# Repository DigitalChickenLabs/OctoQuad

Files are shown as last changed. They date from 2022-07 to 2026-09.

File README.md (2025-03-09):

The OctoQuad is an 8-channel quadrature & pulse width decode module. For quadrature signals, position and velocity can be tracked for all 8 channels simultaneously at up to a 250KHz pulse rate (up to 1 million counts/s). For pulse width signals, pulses up to 65535us are supported. With firmware v3, PWM absolute encoders can be tracked accross multiple revolutions. The FTC Edition MK2 board also has an onboard IMU and absolute localizer algorithm intended for use with deadwheel odometry pods.

The channel inputs and I2C lines are protected from ESD to +/- 15kV (air).

Options for interfacing to OctoQuad are very flexible (I2C only on FTC Ed.):

 - I2C (up to 400KHz bus speed)

 - SPI (up to 1MHz bus speed)

 - UART (ASCII-based protocol, 115200 baud, 10-60Hz data output)

 - USB serial (ASCII-based protocol, 10-60Hz data output)

The OctoQuad is perfect for use cases where there is a need to decode many pulse width or high-speed encoder signals, but doing so directly on the system is not feasible. For example, reading quadrature encoders on a Raspberry Pi can be problematic because Linux is not a real-time operating system and does not guarantee accurate timing. Similarly, decoding many high speed quadrature signals on a microprocessor can consume a significant amount of processor time and requires many digital pins. When using an OctoQuad, this processing is offloaded, leaving your processor free for other tasks and removing the need to worry about precise timing.

**All logic and power is 3.3v only! The OctoQuad is not 5v tolerant!**

The OctoQuad can be powered via or USB or via the 3.3v input pin on the board. All channel connections and the dedicated I2C connector use a JST-PH connector, while the auxiliary header uses a standard 0.1" pin spacing.

A wide range of sample code is available, including for Arduino, Raspberry Pi, and PC.

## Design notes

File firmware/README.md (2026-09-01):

# Download OctoQuad Firmware.

**WARNING: Flashing unofficial firmware may cause permanent damage to the OctoQuad, or to devices to which it is connected.**

## Firmware files

From time to time, official firmware updates for the OctoQuad may be released. 
These Official firmware binaries are found here. 

## Note about Firmware Versions

The OctoQuad FTC Edition MK1 shipped with firmare v2. It can, however, be upgraded to firmware v3 to gain support for CRC data validation. The OctoQuad FTC Edition MK2 shipped with firmware v3. It CANNOT be downgraded to firmware v2.

## Flashing firmware

To flash a firmware image onto the OctoQuad, follow the procedure below:

 - Remove all power and data connections from the OctoQuad.
 - Press and hold the BOOTSEL button (‘B’ on resin printed case)
 - While holding BOOTSEL, connect the OctoQuad to a computer using the micro-USB port
 - Wait until the emulated USB drive appears on the computer. The LED will remain off.
 - Drag-n-drop the firmware image onto the emulated USB drive
 - The OctoQuad will automatically flash the firmware and reboot. Flashing is complete when the emulated USB drive disappears and the status LED begins blinking an interface code.

## Release Notes

### v3.1.0

 - Improves IMU stability on FTC Ed MK2
 - Adds diagnostic parameters for the IMU and MCU uptime

### v3.0.11

 - Improves accuracy of absolute localizer velocity on FTC Ed MK2
 - Improves initial IMU calibration accuracy on FTC Ed MK2

### v3.0.10

 - Initial firmware release supporting OctoQuad FTC Ed MK2 (also backwards compatible with other OctoQuad models, to gain support for CRCs on data)
 - Note the register map changed from v2 and driver software will need to be updated accordingly

### v2.0.15

 - Initial firmware release compatible with original OctoQuad and OctoQuad FTC Ed MK1

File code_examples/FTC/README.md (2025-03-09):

# Note about Firmware Versions

The OctoQuad FTC Edition MK1 shipped with firmare v2. It can, however, be upgraded to firmware v3 to gain support for CRC data validation. The OctoQuad FTC Edition MK2 shipped with firmware v3. It CANNOT be downgraded to firmware v2.

# Using the OctoQuad in the FTC SDK

The FTC SDK has a driver built-in for firmware v2. See the example code shipped with the SDK [here](https://github.com/FIRST-Tech-Challenge/FtcRobotController/blob/master/FtcRobotController/src/main/java/org/firstinspires/ftc/robotcontroller/external/samples/Sensor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).

However, for firmwre v3 (which is required for the OctoQuad FTC Edition MK2), you MUST use the driver supplied in this folder. To use this driver, simply copy&paste it into your TeamCode module, and configure the OctoQuad in your robot configuration as "OctoQuad FW v3".

# OctoQuad FTC Edition MK2 Localizer Quickstart

To quickly get up and runnning with the absolute localizer functions of the MK2 board, review the Localizer Quickstart PDF document located in the documentation directory of this repository.

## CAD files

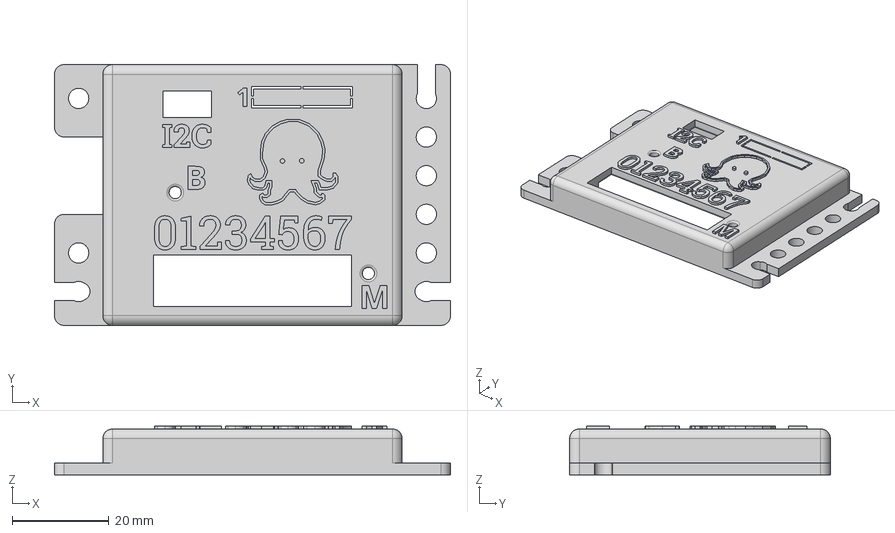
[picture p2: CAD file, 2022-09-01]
mechanical/3D print case/OctoQuad_1.2_SLA_-_Lid.step
82.0 x 54.0 x 10.1 mm

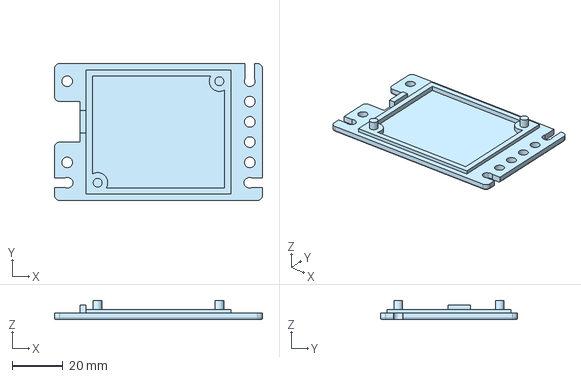
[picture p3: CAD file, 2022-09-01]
mechanical/3D print case/OctoQuad_1.2_SLA_-_Base.step
82.0 x 54.0 x 7.50 mm

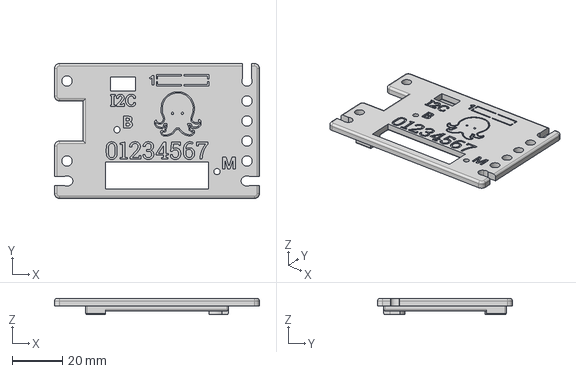
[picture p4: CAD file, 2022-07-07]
mechanical/3D print case/OctoQuad_1.X_FDM_-_Lid.step
82.0 x 54.0 x 6.50 mm

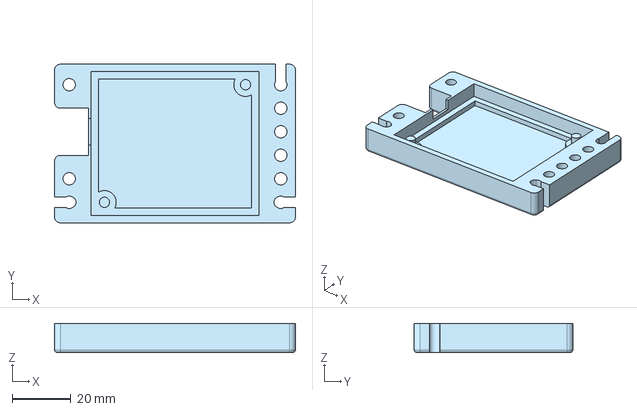
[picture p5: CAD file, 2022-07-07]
mechanical/3D print case/OctoQuad_1.X_FDM_-_Base.step
82.0 x 54.0 x 10.0 mm

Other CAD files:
mechanical/3D print case/OctoQuad_1.2_SLA_-_Base.stl
mechanical/3D print case/OctoQuad_1.X_FDM_-_Base.stl
mechanical/3D print case/OctoQuad_1.X_FDM_-_Lid.stl

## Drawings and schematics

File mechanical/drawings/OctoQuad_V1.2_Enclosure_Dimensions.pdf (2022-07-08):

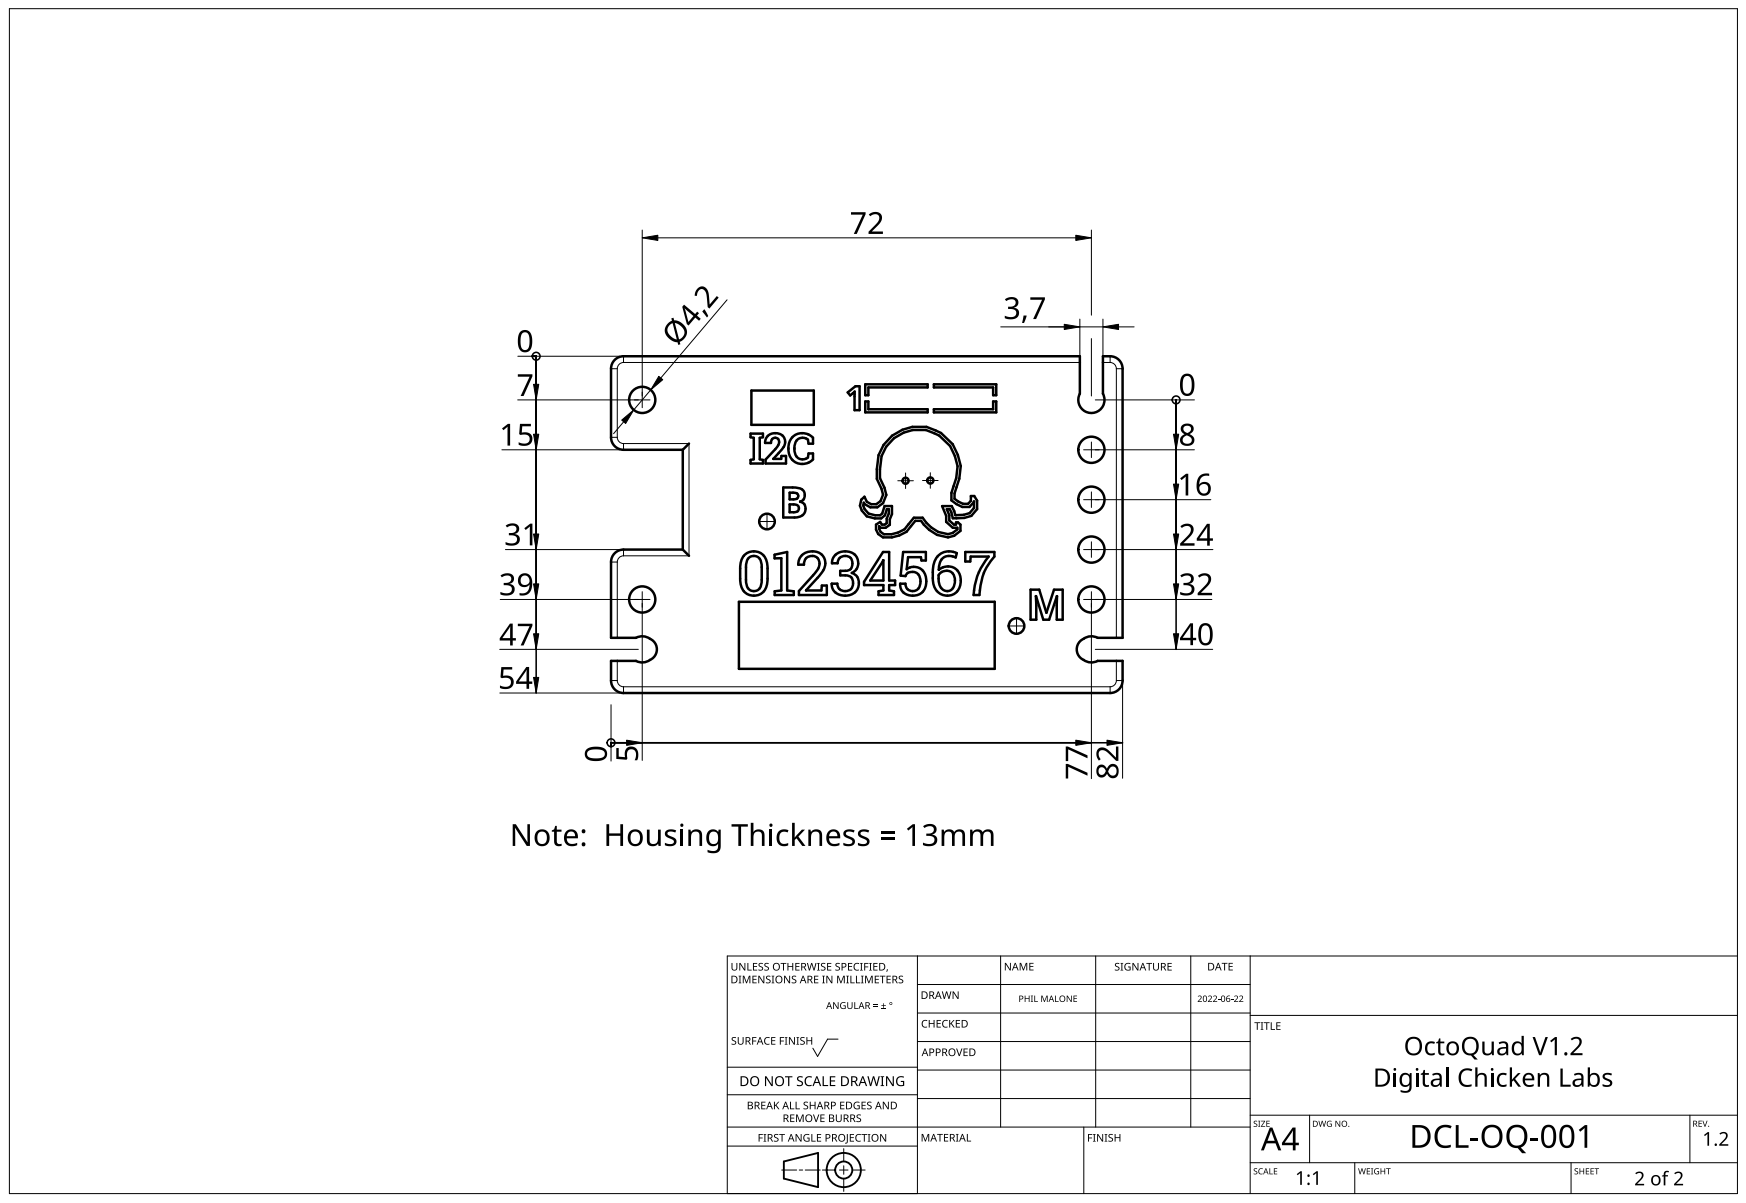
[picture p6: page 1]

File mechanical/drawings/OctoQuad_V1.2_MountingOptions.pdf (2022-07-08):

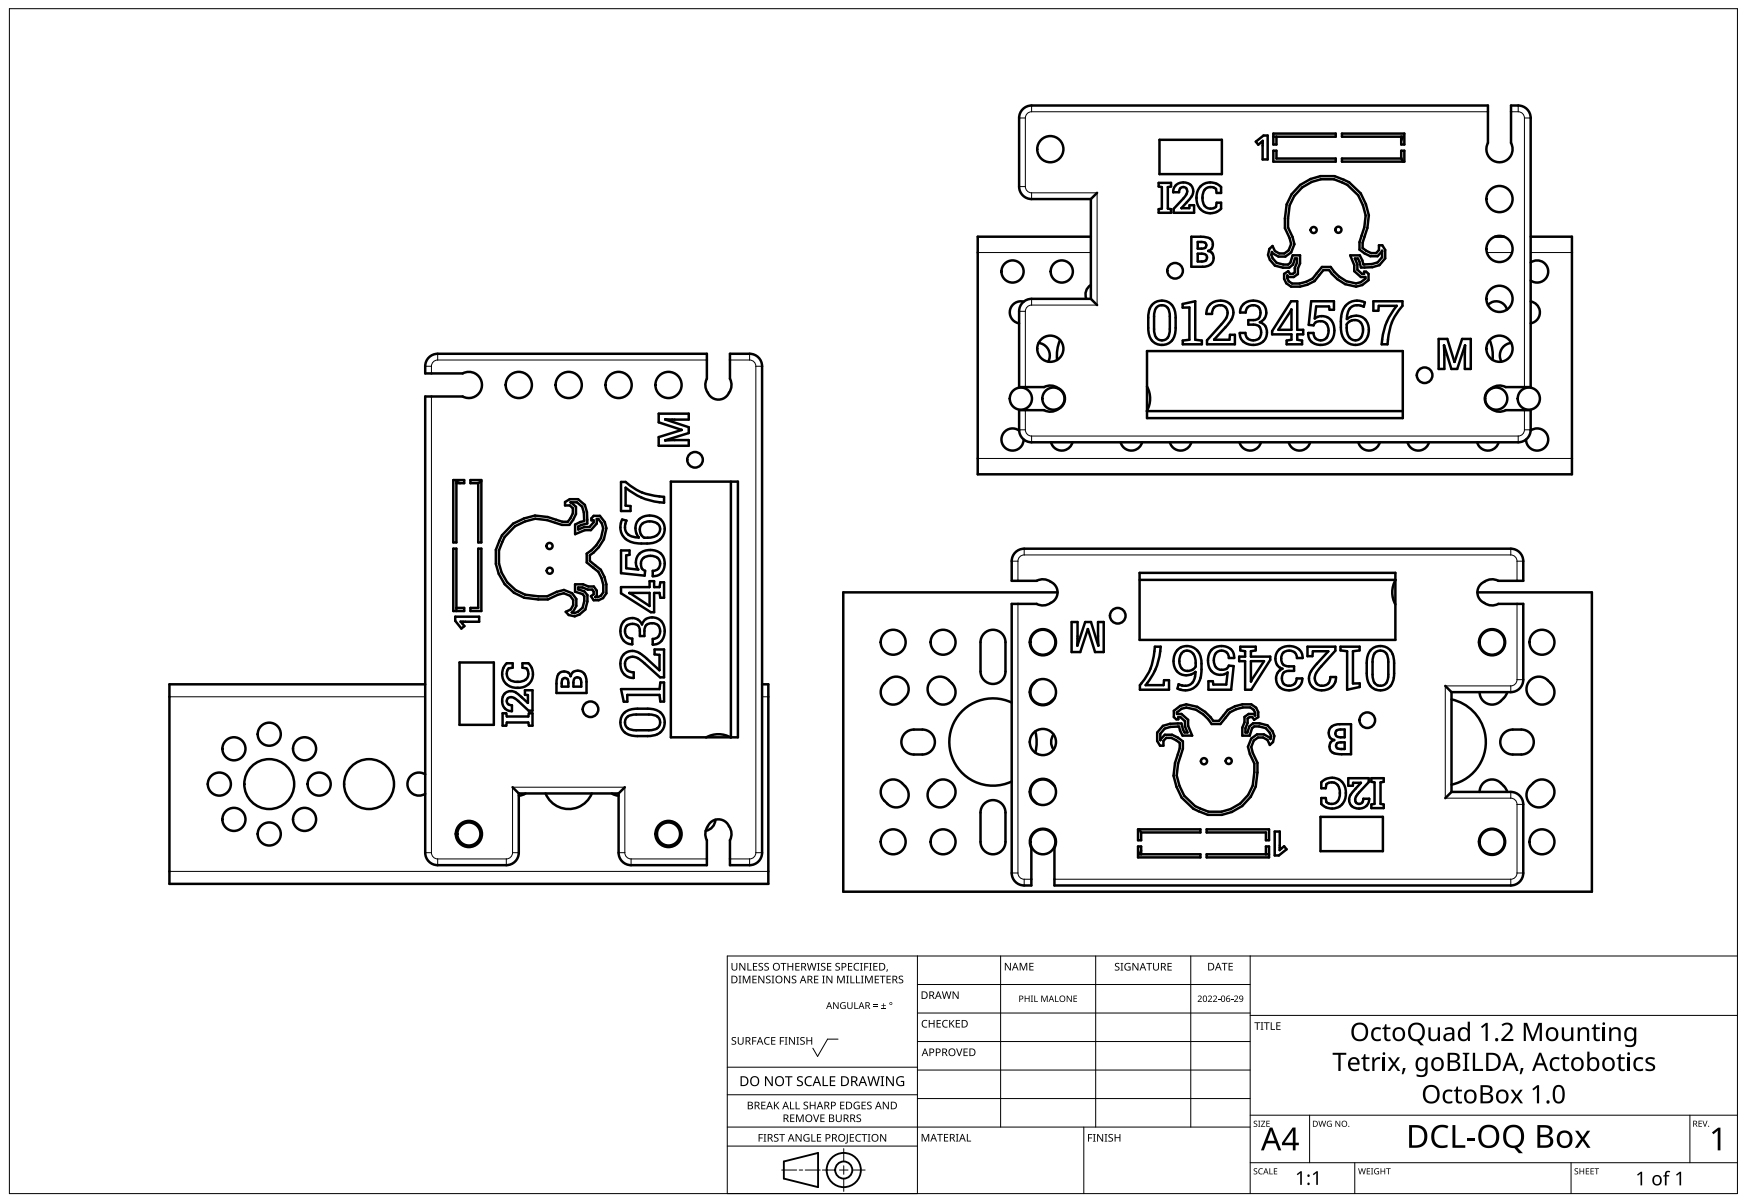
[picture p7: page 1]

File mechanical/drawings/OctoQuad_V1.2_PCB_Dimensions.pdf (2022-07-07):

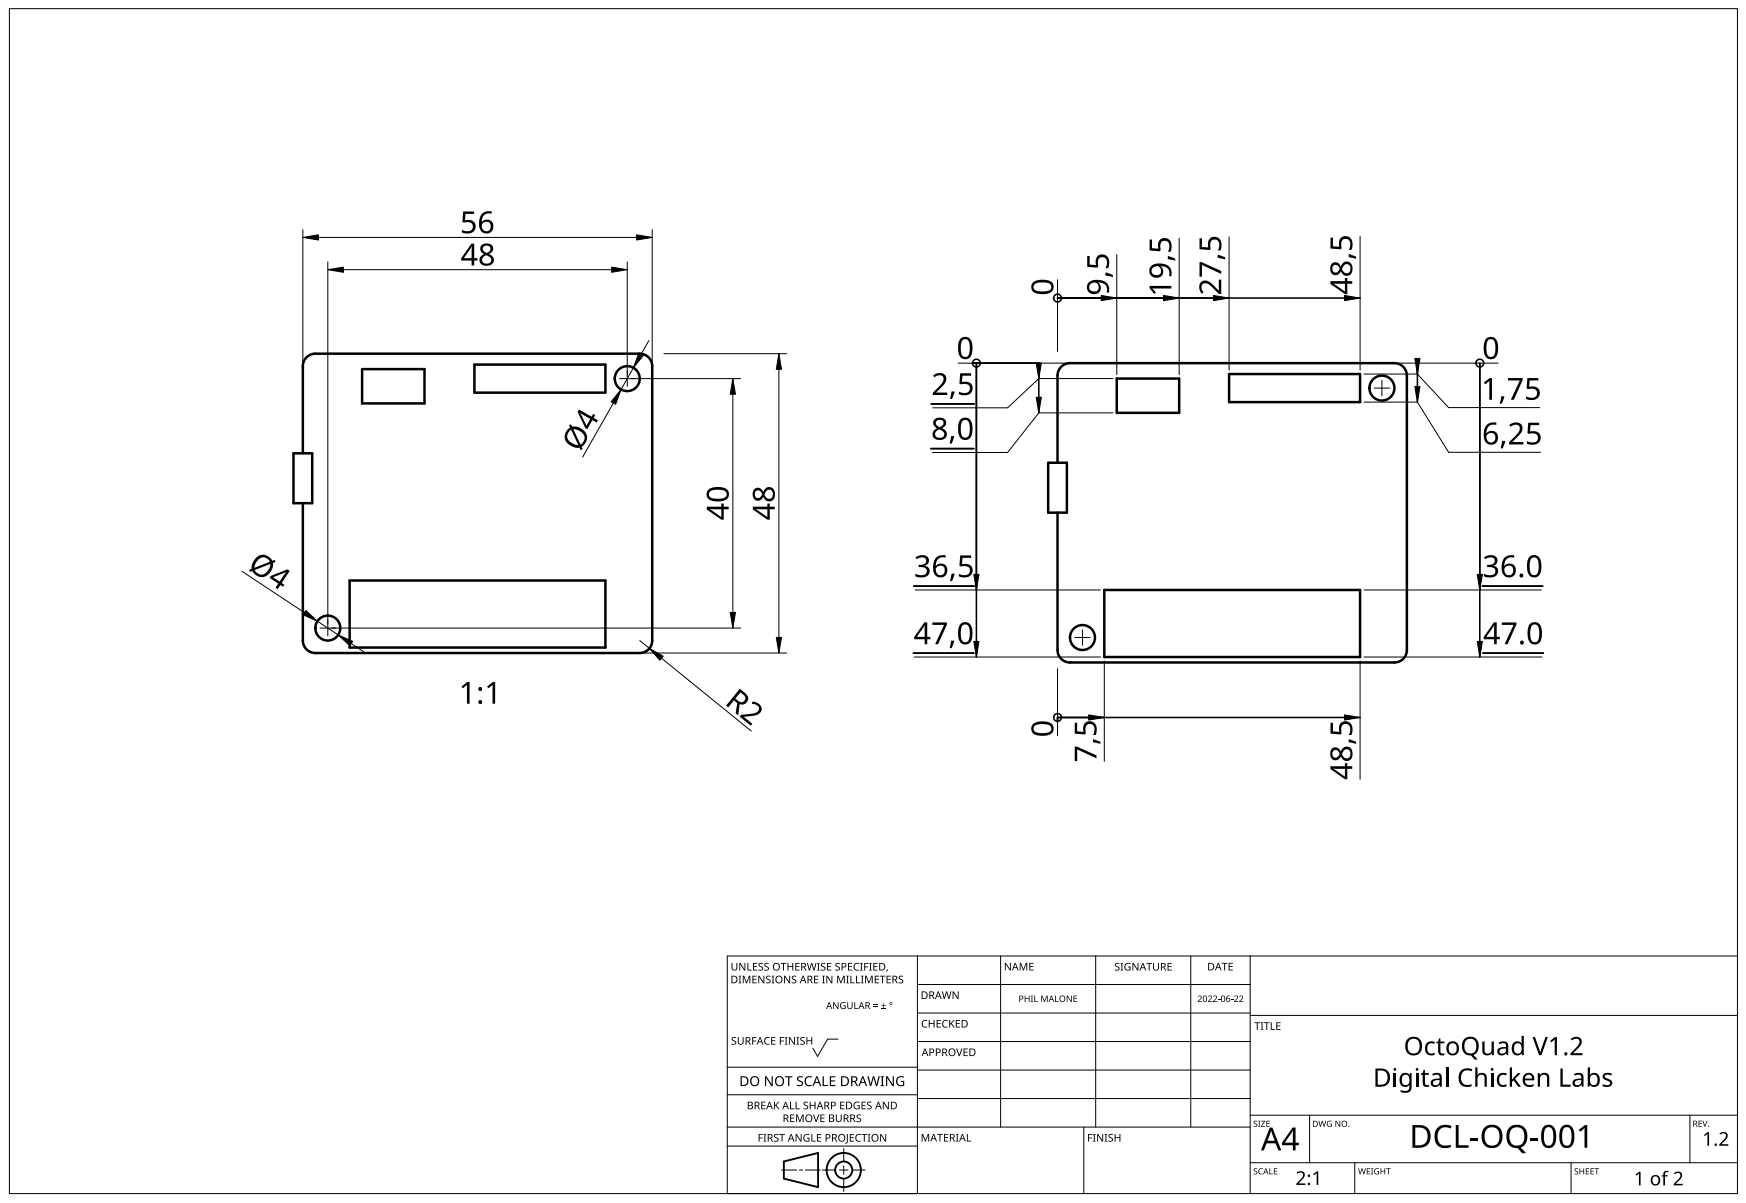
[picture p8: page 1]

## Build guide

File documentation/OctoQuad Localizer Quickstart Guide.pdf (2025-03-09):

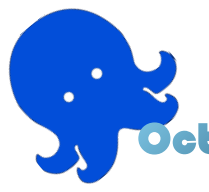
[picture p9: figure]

# OctoQuad Localizer Quickstart

Absolute Localizer Introduction
The OctoQuad FTC Edition MK2 features an onboard IMU and absolute localizer algorithm designed for use with encoders on free-spinning position tracking wheels (“deadwheel odometry pods”) on an FTC robot. The OctoQuad functions as a coprocessor, combining encoder data and IMU data at 1.92KHz to calculate absolute position. This provides excellent position tracking accuracy which is independent of user code execution speed on the host processor. Absolute position data can be queried by the host processor over the I2C interface, along with a cyclic-redundancy-check (CRC) signature to verify the integrity of the received data.

GitHub Repository
This document refers to several files located in the OctoQuad GitHub repository: https://github.com/DigitalChickenLabs/OctoQuad

Absolute Localizer Necessary Configuration
In order to make use of the absolute localizer, the OctoQuad must be informed of some characteristics of your robot and its deadwheel setup.
- Deadwheel encoder ports
- Encoder port directions
- Deadwheel resolutions
- TCP offset
- IMU Scalar
To obtain these values, refer to the setup outline below.

Initial Setup / Calibration Outline
1. Mount the OctoQuad on the robot. Refer to Mounting the OctoQuad on Your Robot.
2. Mount the deadwheels on the robot, one for the X axis and one for the Y axis. Refer to Absolute Coordinate System.
3. Connect the deadwheel encoders to the OctoQuad, making note of the ports on the OctoQuad that you connect them to.
4. Determine if the direction of one (or both) deadwheel encoders must be reversed. Refer to Deadwheel Direction Configuration.

5. Measure the linear resolution of the deadwheel encoders. Refer to Deadwheel Resolution Configuration
6. Measure the IMU heading scalar. Refer to IMU Scalar Calibration.
7. Measure the TCP offset. Refer to Localizer TCP Offset.
8. Plug the determined constants into the LocalizerTest OpMode located in the code_examples/FTC directory of the github repository (https://github.com/DigitalChickenLabs/OctoQuad) and the test localizer accuracy.

Mounting the OctoQuad on Your Robot
The OctoQuad may be mounted on the robot in any of the 6 orientations orthogonal to the direction of gravity. During IMU calibration, the direction of gravity is automatically detected and the appropriate configuration applied to the internal localizer algorithm. The following graphics illustrate acceptable mounting orientations with respect to gravity:

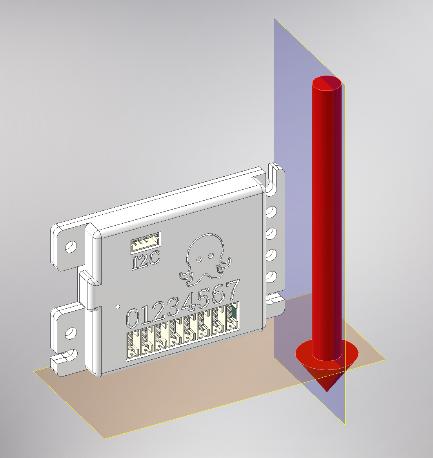
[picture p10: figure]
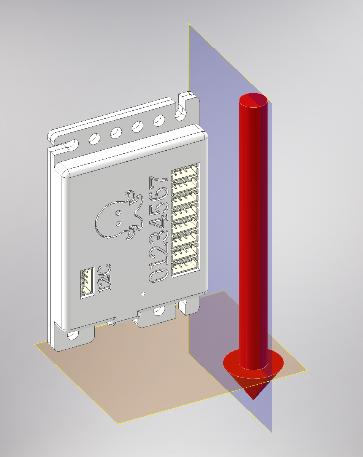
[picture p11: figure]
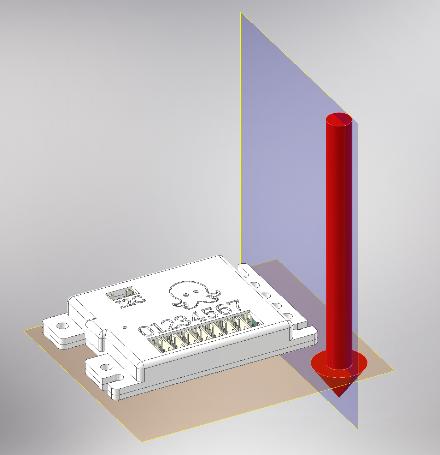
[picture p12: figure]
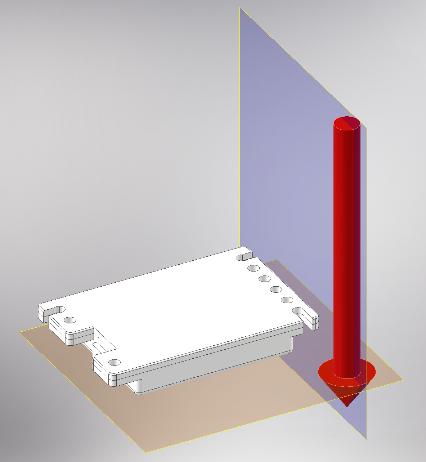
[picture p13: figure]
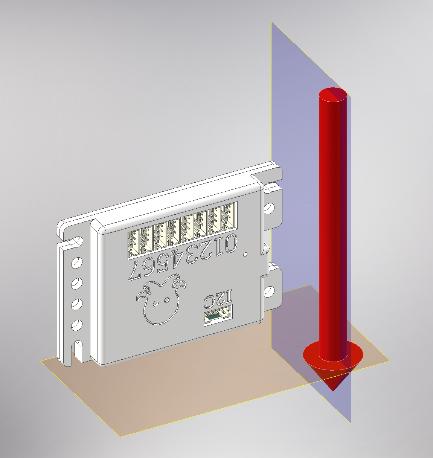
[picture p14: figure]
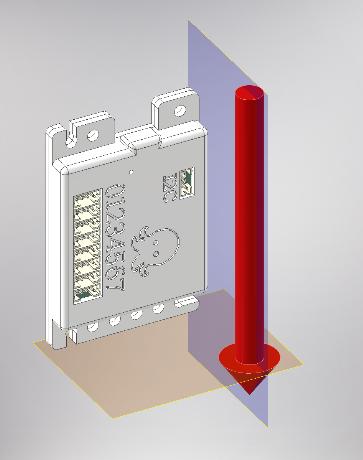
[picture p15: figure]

Absolute Coordinate System
The absolute coordinate system used by the OctoQuad is shown in the figure below. After resetting the localizer, the +X axis points out the front of the robot, and the +Y axis points out the left side of the robot. Counter-clockwise rotation is considered positive. This convention, although at first seemingly counter-intuitive, is chosen for consistency with the cartesian coordinate plane: after calibration, the IMU heading is reset to zero, and moving at an angle of 0 degrees on the cartesian plane means moving in the +X direction.

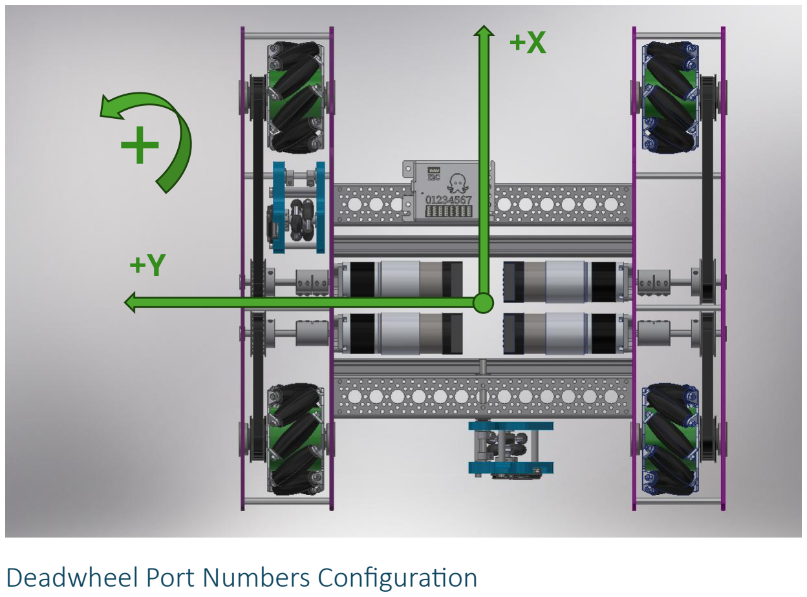
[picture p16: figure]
Deadwheel Port Numbers Configuration

The OctoQuad must be informed of the encoder port numbers to which the deadwheels are connected. To do so, use the following driver function calls when initializing the device:

void setLocalizerPortX(int port)

void setLocalizerPortY(int port)
Deadwheel Direction Configuration
The direction of the encoder ports to which the deadwheels are connected must be configured such that, with the robot oriented at 0 degrees, pushing the robot in the +X direction results in an increasing encoder count on the X deadwheel, and likewise, pushing the robot in the +Y direction results in an increasing encoder count on the Y deadwheel

(see Absolute Coordinate System). A helper OpMode is available to aid in determining this, as well as the deadwheel resolution (see below). If reversing is necessary, use the following driver function call for each deadwheel when initializing the device:

void setSingleEncoderDirection(int port, EncoderDirection direction)
Deadwheel Resolution Configuration
Because the number of deadwheel encoder ticks generated for a given robot travel distance depends on both the resolution of the encoder and diameter of the wheel, the localizer must be informed (for both axes) of how many encoder ticks correspond to one millimeter of travel. Although a theoretical value may be calculated for this based on the hardware used on the robot, it is NOT recommended to do so. Rather, an empirical measurement over several meters of travel is suggested. An OpMode is available which provides a guided process for completing these steps (DeadwheelCalibator in the code_examples/FTC directory of the GitHub repository). (https://github.com/DigitalChickenLabs/OctoQuad) Alternatively, if you already know these constants based on specifications provided by the deadwheel manufacturer, you may use those constantly directly instead. For example, values for GoBilda odometry pods are available here. (https://github.com/goBILDA-Official/FtcRobotController-Add-Pinpoint/blob/goBILDA-Odometry-Driver/TeamCode/src/main/java/org/firstinspires/ftc/teamcode/GoBilda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) Once the constants have been determined, they may be applied using the following driver function calls when initializing the device:

void setLocalizerCountsPerMM_X(float ticksPerMM_x)

void setLocalizerCountsPerMM_Y(float ticksPerMM_y)
IMU Scalar Calibration
The OctoQuad self-calibrates the zero-angular-velocity bias of the IMU. However, it cannot automatically calibrate the angular velocity scale factor for the IMU. It is critical to calculate this scale factor in order to obtain accurate heading data. Incorrect scalars will not cause heading drift – but they will result in the IMU reporting more/less degrees of rotation than it was truly rotated. An OpMode is available which provides a guided process for completing this calibration (HeadingScalarCalibrator in the code_examples/FTC directory of the GitHub repository). (https://github.com/DigitalChickenLabs/OctoQuad) Once the scale factor has been determined, it may be set using the following driver function call:

void setLocalizerImuHeadingScalar(float headingScalar)
Localizer TCP Offset
The Tracking Center Point (TCP) is the “datum point” on the robot to which the robot’s XY displacement relative to the origin of the absolute coordinate system is measured. An important characteristic of the TCP is that it is the point about which a rotation does not influence the reported displacement. Imagine putting an orange sticker on a corner of the robot (call this the TCP). If you then rotate the robot with the orange sticker being the center of rotation, the physical location of the orange sticker will not change. If you measure the displacement of the orange sticker relative to the playing field before and after rotating the robot, it will be exactly the same.
With deadwheel odometry, the initial mathematical location of the TCP is at the intersection of lines drawn through the deadwheels and parallel to their respective

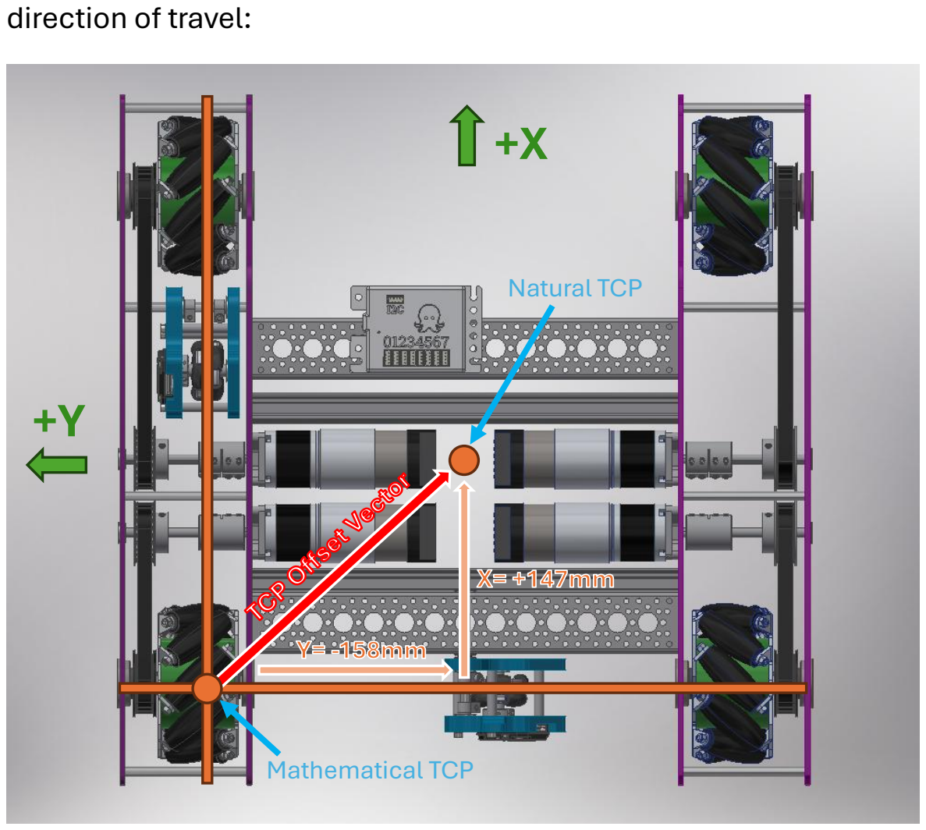
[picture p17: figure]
direction of travel:; Mathematical TCP; Natural TCP

The initial mathematical TCP is located at this intersection because it is the location where, if it is the center of rotation, the odometry wheels experience no normal motion (only tangential). Said another way, rotating about this point causes the odometry wheels to exclusively slide laterally rather than rotate axially. Thus, because there is no axial rotation, the reported XY displacement remains constant.
This initial mathematical location of the TCP can prove rather inconvenient, because it is NOT coincident with the robot’s natural center of rotation, i.e. its geometric center. This means that, initially, the displacement of the robot in the absolute coordinate system is not being measured relative to its natural center of rotation. This has the effect of the reported X and Y positions “wobbling” in a sinusoidal fashion if the robot is rotated about its natural center of rotation. Thus, it is often convenient to, in software, relocate the TCP to be coincident with the robot’s geometric center.
The TCP offsets are defined as the vector which points from the initial mathematical TCP location to the desired/natural TCP location, in the coordinate system defined in Absolute Coordinate System. In the example situation shown in the figure, the X offset is +147mm and the Y offset is -158mm because to relocate the mathematical TCP to the natural TCP, it must be moved <+147, -158> in the coordinate system. These distances can be measured with a tape measure; it is not critical to tracking accuracy for them to be exact.
Once the desired offsets have been determined, they may be applied using the following driver function calls when initializing the device:

void setLocalizerTcpOffsetMM_X(float tcpOffsetMM_X)

void setLocalizerTcpOffsetMM_Y(float tcpOffsetMM_Y)
Localizer Velocity Calculation Interval
The localizer calculates the velocity in the absolute coordinate frame at a fixed interval (by default, 25ms). Longer periods give higher resolution with more latency, shorter periods give lower resolution with less latency. If you wish to change this interval from its default value, use the following driver function call when initializing the device:

void setLocalizerVelocityIntervalMS(int ms)
CRC Data Integrity Check
The I2C bus protocol does not have any data integrity guarantee mechanisms built into it by default. In FTC, ESD events can cause corrupted I2C data. Additionally, it has been observed that the Control Hub and Expansion Hub appear to have a hardware bug wherein motor switching noise can cause the I2C peripheral to become confused and send invalid I2C clock pulses that violate timing, which also causes corrupted data. One frequently observed symptom of this is getting “NaN” results from an I2C device. In order to mitigate these issues, the OctoQuad supplies a CRC signature along with the data in order to validate the integrity of the data on the receiving end.

Both the EncoderDataBlock and LocalizerDataBlock data structures contain a crcOk
boolean field which reports whether or not the data is valid. If this flag is not set, you should throw away the data and attempt a read again.

Device Initialization
When initializing the device from user code, follow the following procedure (this is also illustrated in the LocalizerTest OpMode located in the code_examples/FTC directory of the github repository): (https://github.com/DigitalChickenLabs/OctoQuad)
1. Retrieve the device handle from the HardwareMap
2. Configure all necessary localizer parameters (refer to Absolute Localizer Necessary Configuration)
3. Apply the parameters and calibrate the IMU by calling
resetLocalizerAndCalibrateIMU()
4. Wait for the localizer status to report RUNNING before querying position data
5. Make sure to check crcOk when polling position data!

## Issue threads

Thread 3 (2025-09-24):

Spurious firmware version numbers from an FTC MK1

manthey, 2025-09-24:
Our FTC team (Robovines 6955 -- I'm a programming mentor) has been using the FTC MK1 octoquad since last season.  We specifically are using it with 3 gobilda odopods.  We got occasional spurious values (seemingly bit flips) through the i2c bus, and had added our own code to detect when the values were clearly wrong and ignore them (this mostly worked but occasionally we would take a modestly wrong value).

We just upgraded to the V3 firmware and are using the code provided from this library.  The `isDataValid()` method works as desired -- when that check passes, all of our data looks good.

Fairly often, however, the driver control hub prints a warning about an incompatible firmware version (the "OctoQuad is running a different major firmware version than this driver was built for ..." message or the "OctoQuad does not report correct CHIP_ID value" message).  Printing the firmware version string, we see that it often has bad values (often 3.0.10 as we'd expect but sometimes 131.0.10 and sometimes 127.255.255).  We get the same results regardless of which rev hub or expansion hub and which i2c port we plug into.  This happens even when we aren't operating motors.  Other i2c devices are plugged in to other i2c ports.

Have you seen this before?  It isn't causing any functional issue, because we guard the actual reads with the `isDataValid` method.  We can obviously suppress the warning messages, but we'd rather have less spurious values.

Thank you.

Windwoes, 2025-09-25:
Hey there - we have seen those errors happen rarely before, but in those instances, the reported values were all zeros and it appeared the I2C controller in the Expansion Hub had gotten into a bad state.

Getting seemingly corrupted I2C frames even when not running motors is a head scratcher for sure. Do you have any equipment (oscilloscope or logic analyzer) to capture what is actually happening on the bus?

manthey, 2025-09-25:
Yes -- I'll see if I can put an o-scope on it at our next meeting and see if I can learn what is going on.  I'll also try it on a completely different control hub with a different connector.

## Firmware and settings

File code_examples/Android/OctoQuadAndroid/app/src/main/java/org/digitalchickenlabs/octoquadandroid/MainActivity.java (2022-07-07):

/*
 * Copyright (c) 2022 DigitalChickenLabs
 *
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
 * The above copyright notice and this permission notice shall be included in all
 * copies or substantial portions of the Software.
 * THE SOFTWARE IS PROVIDED "AS IS", WITHOUT WARRANTY OF ANY KIND, EXPRESS OR
 * IMPLIED, INCLUDING BUT NOT LIMITED TO THE WARRANTIES OF MERCHANTABILITY,
 * FITNESS FOR A PARTICULAR PURPOSE AND NONINFRINGEMENT. IN NO EVENT SHALL THE
 * AUTHORS OR COPYRIGHT HOLDERS BE LIABLE FOR ANY CLAIM, DAMAGES OR OTHER
 * LIABILITY, WHETHER IN AN ACTION OF CONTRACT, TORT OR OTHERWISE, ARISING FROM,
 * OUT OF OR IN CONNECTION WITH THE SOFTWARE OR THE USE OR OTHER DEALINGS IN THE
 * SOFTWARE.
 */

package org.digitalchickenlabs.octoquadandroid;

import android.app.Activity;
import android.content.Intent;
import android.os.Bundle;
import android.view.View;
import android.widget.Button;
import android.widget.LinearLayout;
import android.widget.TextView;

import java.nio.charset.StandardCharsets;
import java.util.ArrayList;
import java.util.concurrent.CountDownLatch;

public class MainActivity extends Activity implements UsbCdcAcmSerialPortManager.Callback
{
    UsbCdcAcmSerialPortManager serialPortManager;

    TextView connectionStatus;
    LinearLayout layoutEncoders;
    TextView enc0, enc1, enc2, enc3, enc4, enc5, enc6, enc7;
    Button btnReset;

    UsbCdcAcmSerialPort octoquad;

    UiUpdaterThread uiUpdaterThread;

    @Override
    protected void onCreate(Bundle savedInstanceState)
    {
        super.onCreate(savedInstanceState);
        setContentView(R.layout.activity_main);

        connectionStatus = (TextView) findViewById(R.id.connectionStatus);
        layoutEncoders = (LinearLayout) findViewById(R.id.encoders);
        btnReset = (Button) findViewById(R.id.btnReset);
        enc0 = (TextView) findViewById(R.id.enc0);
        enc1 = (TextView) findViewById(R.id.enc1);
        enc2 = (TextView) findViewById(R.id.enc2);
        enc3 = (TextView) findViewById(R.id.enc3);
        enc4 = (TextView) findViewById(R.id.enc4);
        enc5 = (TextView) findViewById(R.id.enc5);
        enc6 = (TextView) findViewById(R.id.enc6);
        enc7 = (TextView) findViewById(R.id.enc7);

        layoutEncoders.setVisibility(View.INVISIBLE);

        serialPortManager = UsbCdcAcmSerialPortManager.getInstance(this);
        serialPortManager.registerCallback(this);

        ArrayList<UsbCdcAcmSerialPort> ports = serialPortManager.getCurrentlyKnownDevices();

        if(ports.size() > 0)
        {
            onDeviceConnected(ports.get(0));
        }

        btnReset.setOnClickListener(new View.OnClickListener()
        {
            @Override
            public void onClick(View v)
            {
                synchronized (MainActivity.this)
                {
                    if(uiUpdaterThread != null)
                    {
                        uiUpdaterThread.sendCommand('R');
                    }
                }
            }
        });
    }

    @Override
    protected void onNewIntent(Intent intent)
    {
        super.onNewIntent(intent);
        serialPortManager.onNewIntent(intent);
    }

    @Override
    protected void onDestroy()
    {
        super.onDestroy();
        serialPortManager.unregisterCallback(this);
    }

    @Override
    public synchronized void onDeviceConnected(UsbCdcAcmSerialPort dev)
    {
        if(octoquad == null)
        {
            octoquad = dev;
            uiUpdaterThread = new UiUpdaterThread(octoquad);
            uiUpdaterThread.start();

            layoutEncoders.setVisibility(View.VISIBLE);
            connectionStatus.setText("OctoQuad Connected");
            connectionStatus.setTextColor(getColor(R.color.colorConnected));
        }
    }

    @Override
    public synchronized void onDeviceDisconnected(UsbCdcAcmSerialPort dev)
    {
        if(dev == octoquad)
        {
            if(uiUpdaterThread != null)
            {
                uiUpdaterThread.shutdownAndAwaitTermination();
                uiUpdaterThread = null;
                octoquad = null;

                layoutEncoders.setVisibility(View.INVISIBLE);
                connectionStatus.setText("OctoQuad Not Connected");
                connectionStatus.setTextColor(getColor(R.color.colorNotConnected));
            }
        }
    }

    @Override
    public void onDeviceOpenFailed(UsbCdcAcmSerialPort dev, UsbCdcAcmSerialPort.OpenResultCode code)
    {

    }

    class UiUpdaterThread extends Thread
    {
        CountDownLatch latch = new CountDownLatch(1);
        byte[] readBuf = new byte[1];
        byte[] lineBuf = new byte[256];
        int lineBufIdx = 0;

        UsbCdcAcmSerialPort port;

        boolean uiUpdateRunning = false;

        public UiUpdaterThread(UsbCdcAcmSerialPort port)
        {
            this.port = port;
        }

        public void shutdownAndAwaitTermination()
        {
            UiUpdaterThread.this.interrupt();
            try {
                latch.await();
            } catch (InterruptedException e) {
                e.printStackTrace();
            }
        }

        void sendCommand(char cmd)
        {
            port.writeDisplacingIfNeeded(new byte[]{(byte)cmd}, 0, 1);
        }

        // Parse the CSV encoder string into an array
        public int[] parseEncoderString(String string)
        {
            String[] parts = string.split(",");
            int[] encoders = new int[8];

            for(int i = 0; i < 8; i++)
            {
                encoders[i] = Integer.parseInt(parts[i]);
            }

            return encoders;
        }

        @Override
        public void run()
        {
            try
            {
                // Synchronize to stream
                for(;;)
                {
                    port.read(readBuf, 0, 1);
                    if(readBuf[0] == '\n') break;
                }

                // Turn on fast mode
                sendCommand('F');

                while (!Thread.currentThread().isInterrupted())
                {
                    port.read(readBuf, 0, 1);
                    lineBuf[lineBufIdx] = readBuf[0];
                    lineBufIdx++;

                    // Did we hit the end of the line?
                    if(readBuf[0] == '\n')
                    {
                        String line = new String(lineBuf, 0,lineBufIdx-2, StandardCharsets.US_ASCII); // Trim off "\r\n"
                        lineBufIdx = 0;
                        final int[] encoders = parseEncoderString(line);

                        if(!uiUpdateRunning)
                        {
                            runOnUiThread(new Runnable()
                            {
                                @Override
                                public void run()
                                {
                                    try
                                    {
                                        enc0.setText("Encoder 0: " + encoders[0]);
                                        enc1.setText("Encoder 1: " + encoders[1]);
                                        enc2.setText("Encoder 2: " + encoders[2]);
                                        enc3.setText("Encoder 3: " + encoders[3]);
                                        enc4.setText("Encoder 4: " + encoders[4]);
                                        enc5.setText("Encoder 5: " + encoders[5]);
                                        enc6.setText("Encoder 6: " + encoders[6]);
                                        enc7.setText("Encoder 7: " + encoders[7]);
                                    }
                                    finally
                                    {
                                        uiUpdateRunning = false;
                                    }
                                }
                            });
                        }
                    }
                }
            }
            catch (ByteFIFO.ShutdownException | InterruptedException e)
            {
                e.printStackTrace();
            }
            finally
            {
                latch.countDown();
            }
        }
    }
}

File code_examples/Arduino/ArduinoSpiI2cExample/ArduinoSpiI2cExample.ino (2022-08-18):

/*
 * Copyright (c) 2022 DigitalChickenLabs
 *
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
 * The above copyright notice and this permission notice shall be included in all
 * copies or substantial portions of the Software.
 * THE SOFTWARE IS PROVIDED "AS IS", WITHOUT WARRANTY OF ANY KIND, EXPRESS OR
 * IMPLIED, INCLUDING BUT NOT LIMITED TO THE WARRANTIES OF MERCHANTABILITY,
 * FITNESS FOR A PARTICULAR PURPOSE AND NONINFRINGEMENT. IN NO EVENT SHALL THE
 * AUTHORS OR COPYRIGHT HOLDERS BE LIABLE FOR ANY CLAIM, DAMAGES OR OTHER
 * LIABILITY, WHETHER IN AN ACTION OF CONTRACT, TORT OR OTHERWISE, ARISING FROM,
 * OUT OF OR IN CONNECTION WITH THE SOFTWARE OR THE USE OR OTHER DEALINGS IN THE
 * SOFTWARE.
 */

#include <Arduino.h>
#include <Wire.h>
#include <SPI.h>
#include "octoquad.h"
#include "octoquad.c"

// ---------------------------------------------------------------------------------
//                               PLATFORM-SPECIFIC HAL
//----------------------------------------------------------------------------------

#define MY_SPI_SS_PIN 7

static bool platform_i2c_read_registers(const uint8_t addr, const uint8_t reg, uint8_t n, uint8_t* const dst)
{
    Wire.beginTransmission(addr);
    Wire.write(reg);
    Wire.endTransmission();
    Wire.requestFrom(addr, n);

    while(Wire.available() < n);

    for(int i = 0; i < n; i++)
    {
        dst[i] = Wire.read();
    }

    return true;
}

static bool platform_i2c_write_registers(const uint8_t addr, const uint8_t reg, const uint8_t* const src, const uint8_t n)
{
    Wire.beginTransmission(addr);
    Wire.write(reg);
    Wire.write(src, n);
    Wire.endTransmission();
    return true;
}

static bool platform_spi_write_blocking(const uint8_t* const src, uint8_t n)
{
    uint8_t scratch[n];
    memcpy(scratch, src, n);
    SPI.transfer(scratch, n); // Avoid trashing src
    return true;
}

static bool platform_spi_write_read_blocking(const uint8_t* const src, uint8_t* const rx, uint8_t n)
{
    memcpy(rx, src, n);
    SPI.transfer(rx, n); // In place update
    return true;
}

static void platform_sleep_us(const uint16_t us)
{
    delayMicroseconds(us);
}

static void platform_sleep_ms(const uint16_t ms)
{
    delay(ms);
}

static void platform_spi_cs_assert(bool assert)
{
    if(assert)
    {
        digitalWrite(MY_SPI_SS_PIN, 0);
    }
    else
    {
        digitalWrite(MY_SPI_SS_PIN, 1);
    }
}

// ---------------------------------------------------------------------------------
//                               HELPER FUNCTIONS
//----------------------------------------------------------------------------------

void setup_spi_interface()
{
    // Configure slave select pin as output
    pinMode(MY_SPI_SS_PIN, OUTPUT);

    // We don't want to talk to the OctoQuad just yet
    platform_spi_cs_assert(false);

    // Configure the SPI peripheral
    SPI.begin();
    SPI.beginTransaction(SPISettings(1000 * 1000, MSBFIRST, SPI_MODE3));
}

void setup_i2c_interface()
{
    // Join I2C as bus master
    Wire.begin();
}

// ---------------------------------------------------------------------------------
//                               MAIN
//----------------------------------------------------------------------------------

// CHOOSE INTERFACE MODE HERE
static OctoQuadInterface INTERFACE_CHOICE = OCTOQUAD_INTERFACE_SPI;

// For use with sprintf
char strBuf[256];

void setup()
{
    if(INTERFACE_CHOICE == OCTOQUAD_INTERFACE_SPI)
    {
        setup_spi_interface();
    }
    else if(INTERFACE_CHOICE == OCTOQUAD_INTERFACE_I2C)
    {
        setup_i2c_interface();
    }

    // Define the platform HAL implementation for the OctoQuad driver
    OctoQuadPlatformImpl platform = {
            .i2c_read_registers = &platform_i2c_read_registers,
            .i2c_write_registers = &platform_i2c_write_registers,
            .spi_write_blocking = &platform_spi_write_blocking,
            .spi_write_read_blocking = &platform_spi_write_read_blocking,
            .spi_cs_assert = &platform_spi_cs_assert,
            .sleep_us = &platform_sleep_us,
            .sleep_ms = &platform_sleep_ms
    };

    // Init the OctoQuad driver
    octoquad_init(INTERFACE_CHOICE, platform);

    // Init USB serial
    Serial.begin(115200);

    // Wait for PC connection
    uint8_t counter = 0;
    while(!Serial.available())
    {
        sprintf(strBuf, "OctoQuad Arduino example... send any char to continue [%3d]\r\n", counter);
        Serial.print(strBuf);
        delay(30);
        counter++;
    }

    // Check the CHIP_ID
    uint8_t chipId;
    if(!octoquad_get_chip_id(&chipId)) goto error;

    if(chipId == OCTOQUAD_CHIP_ID)
    {
        sprintf(strBuf, "CHIP_ID reports 0x%X as expected\r\n", chipId);
        Serial.print(strBuf);
    }
    else
    {
        sprintf(strBuf, "CHIP_ID check failed, got 0x%X expect 0x%X\r\n", chipId, OCTOQUAD_CHIP_ID);
        Serial.print(strBuf);
        goto error;
    }

    // Read the firmware version
    OctoQuadFwVersion firmwareVersion;
    if(!octoquad_get_fw_version(&firmwareVersion)) goto error;

    // Print to console
    sprintf(strBuf, "OctoQuad Reports FW v%d.%d.%d\r\n", firmwareVersion.maj, firmwareVersion.min, firmwareVersion.eng);
    Serial.print(strBuf);

    // Check if that FW version is compatible
    if(firmwareVersion.maj != OCTOQUAD_DRIVER_SUPPORTED_FW_VERSION_MAJ)
    {
        sprintf(strBuf, "Cannot continue: The connected OctoQuad is running a firmware with a different major version than this program expects (got %d, expect %d)\r\n", firmwareVersion.maj, OCTOQUAD_DRIVER_SUPPORTED_FW_VERSION_MAJ);
        Serial.print(strBuf);
        goto error;
    }

    OctoQuadChannelBankMode channelBankMode;
    if(!octoquad_get_channel_bank_mode(&channelBankMode)) goto error;
    sprintf(strBuf, "Channel Bank Mode = %d\r\n", channelBankMode);
    Serial.print(strBuf);

    OctoQuadI2cRecoveryMode recoveryMode;
    if(!octoquad_get_i2c_recovery_mode(&recoveryMode)) goto error;
    sprintf(strBuf, "I2C Recovery Mode = %d\r\n", recoveryMode);
    Serial.print(strBuf);

    for(int i = ENCODER_IDX_MIN; i <= ENCODER_IDX_MAX; i++)
    {
        uint8_t intvl;
        if(!octoquad_get_velocity_measurement_intvl(i, &intvl)) goto error;
        sprintf(strBuf, "Channel %d velocity sample interval = %d\r\n", i, intvl);
        Serial.print(strBuf);
    }

    for(int i = ENCODER_IDX_MIN; i <= ENCODER_IDX_MAX; i++)
    {
        OctoQuadChannelPulseWidthParams params;
        if(!octoquad_get_channel_pulse_width_params(i, &params)) goto error;
        sprintf(strBuf, "Channel %d pulse min/max = %d/%d\r\n", i, params.min, params.max);
        Serial.print(strBuf);
    }

    bool channelDirections[8];
    octoquad_get_all_channel_directions(channelDirections);

    for(int i = ENCODER_IDX_MIN; i <= ENCODER_IDX_MAX; i++)
    {
        sprintf(strBuf, "Channel %d reverse = %d\r\n", i, channelDirections[i]);
        Serial.print(strBuf);
    }
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

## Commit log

2022-07-08 Fix incorrect target register for some operations
    [octoquad.c, octoquad.h]
2022-08-12 Fix broken regsiter write for SPI mode
    [octoquad.c]
2022-08-16 Move usages of embededd driver to symlink and update Arduino example
2022-08-16 Update RaspberryPi examples for FW 2.x
2022-08-31 Added SLA versions of enclosure
    [OctoQuad_1.2_SLA_-_Base.step, OctoQuad_1.2_SLA_-_Base.stl, OctoQuad_1.2_SLA_-_Lid.step]
